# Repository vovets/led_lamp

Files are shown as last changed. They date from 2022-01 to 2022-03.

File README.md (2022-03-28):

# led_lamp

Slightly overengineered battery powered LED lamp for reading

## Introduction

The project was born when I acquired a battery powered lamp for reading and very soon found its deficiencies.

* It changed brightness as battery drained.
* It had only 2 brightness level, both too bright.
* Its efficiency which I define as a ratio of power coming to LED to power coming from battery is only 0.7.

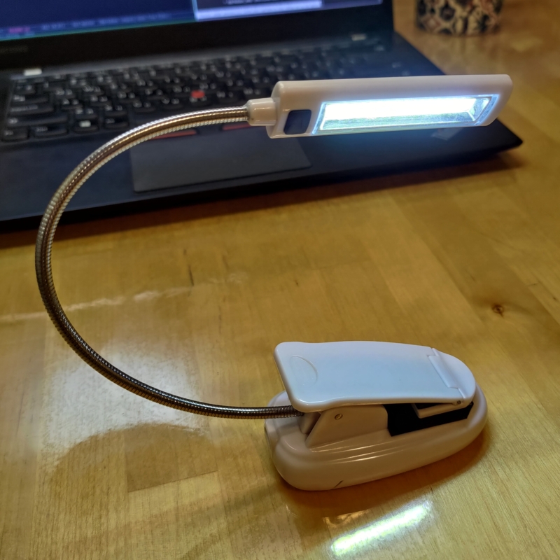
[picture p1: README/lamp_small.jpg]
The Lamp


So I decided to implement my own led driver with mcu control. It actually required some iterations of software and hardware to come up with what is being described here.

## Requirements

* The brightness should be constant as long as the battery voltage under load is higher than some sensible threshold, say 3V. As battery is drained further brightness may gradually decrease.
* When the battery voltage decreases lower than some defined threshold lamp should provide visual indication that battery needs replacement or charging.
* There should be UI for setting the desired brightness level. The brightness levels may be discreet but then there should be enough different levels. The selected brightness level must be kept across the lamp ON-OFF cycles.
* When the battery is completely drained the lamp should clearly indicate this fact and then turn off to prevent battery damage. Lamp should not turn on with a drained battery but provide indication of the flat battery if possible.
 
## Hardware

The lamp consists of "base" with usb connector and batteries, and "head" with a LED panel and a tactile button. The head connected with the base using flexible metallic tube.

### Original hardware

Original electronics consists of two pcbs, one in head and one in base.
The one in the base contains a usb connector, a diode which blocks current from battery to usb VBUS and a 2 Ohm series resistor.
The head pcb contains unmarked chip which obviously provides PWM capability and on/off/mode logic. The LED panel is controlled by a n-channel mosfet. The gate of the mosfet is controlled by the chip. There is also 2 Ohm resistor in series with LED. I assume that the chip is a some obscure uC and there is no LED current limiting except for series resistors.

### Custom hardware

My custom hardware consists of one pcb which contains all the active elements. I also used original pcbs for passive connections. The original base board is used with all parts removed except USB connector. The original head pcb is also cleared of original parts except the button switch and modified using knife and modwire to provide necessary connections. 3 thin wires run inside the connecting tube.

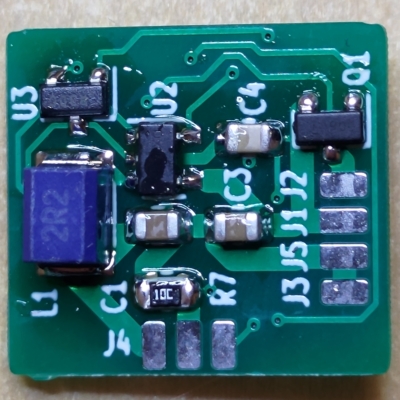
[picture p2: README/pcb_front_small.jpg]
PCB Front
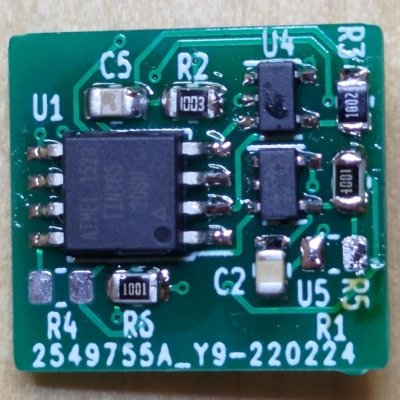
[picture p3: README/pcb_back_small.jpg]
PCB Back
 

*My custom pcb front and back respectively*

### Custom hardware schematics discussion

The parts I used to design the schematics are those I had at my disposal and/or could easyly source locally.

#### DC-DC converter

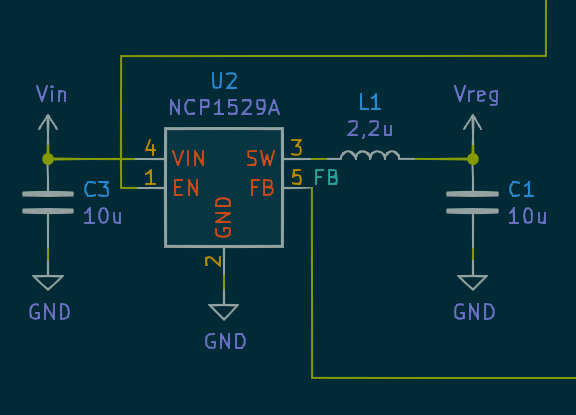
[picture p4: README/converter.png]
DC-DC buck converter


This is the module that provides LED current regulation. Efficiency of the whole device depends mostly on this module.
[Converter chip](hw/datasheet/NCP1529.pdf) may be disabled by MCU via EN pin. In disabled state it consumes just 0.3 uA. Output voltage is controlled by voltage on the FB pin. It is connected to the LED current amplifier.

#### LED current amplifier

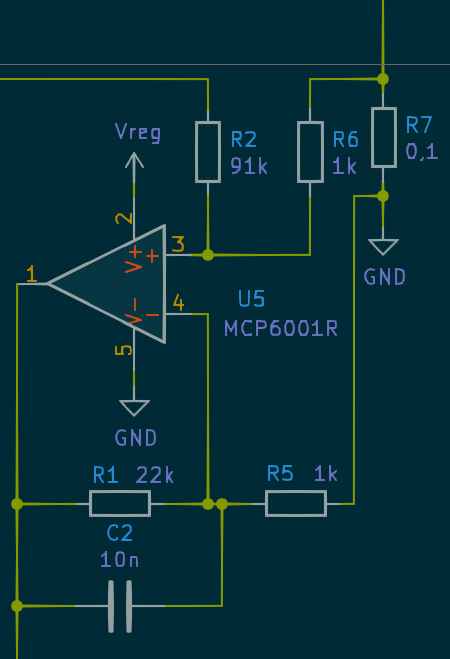
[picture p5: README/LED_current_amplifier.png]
LED current amplifier


The LED current amlifier is built using [MCP6001R](hw/datasheet/MCP6001_1R_1U_2_4.pdf "MCP6001R") CMOS opamp. It amplifies voltage drop on 0.1 Ohm current sensing resistor *R7*, which is fed to the non-inverting input. The non-inverting input is also biased by the DAC module output voltage via *R2*. This arrangement allows to set current regulation point by programming DAC output. When DAC output is 0V, amplifier outputs 0.6V for 250mA LED current. When the voltage on DAC output is at max, which is slightly below 2.5V, the current regulated at approximately 10mA point. It corresponds to the lowest brightness of the lamp.
So the maximum current is 250mA and the minimum is 10mA.

#### DAC

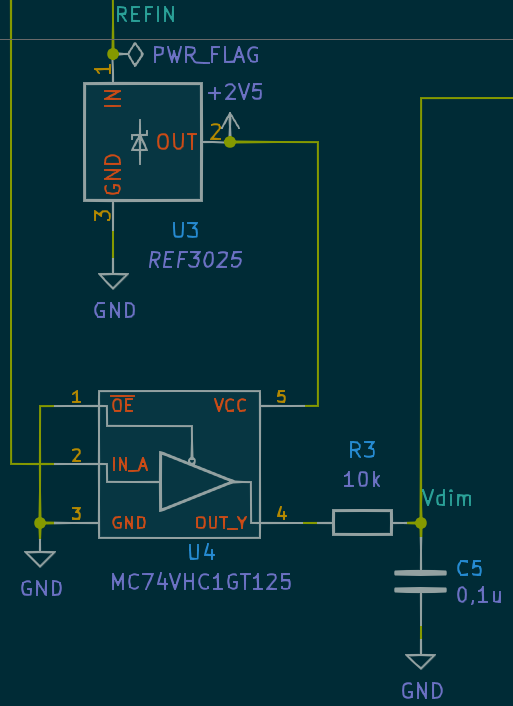
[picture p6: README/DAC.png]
DAC


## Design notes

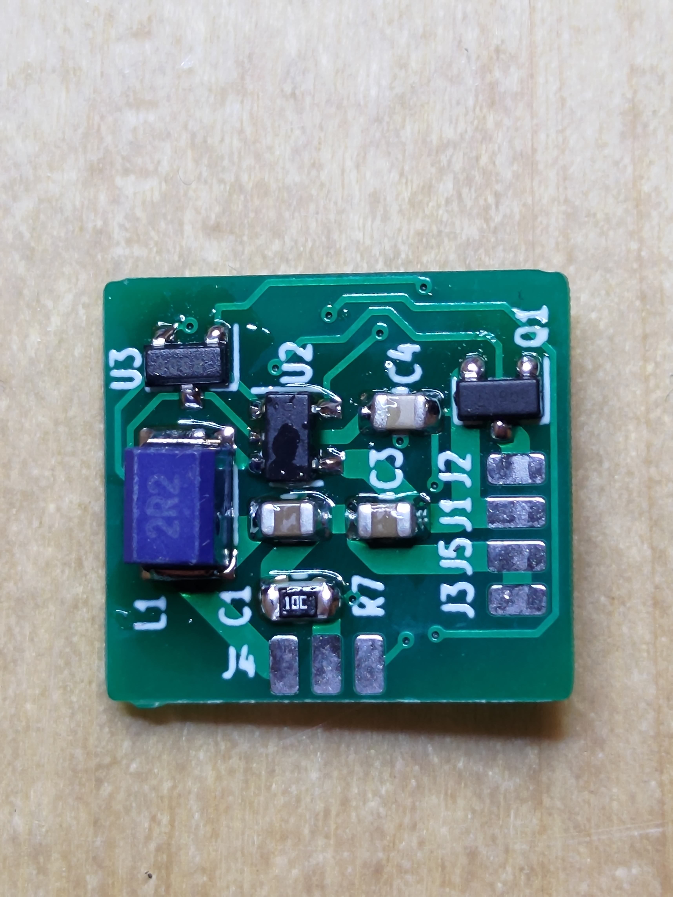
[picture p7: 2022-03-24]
README/pcb_front.jpg

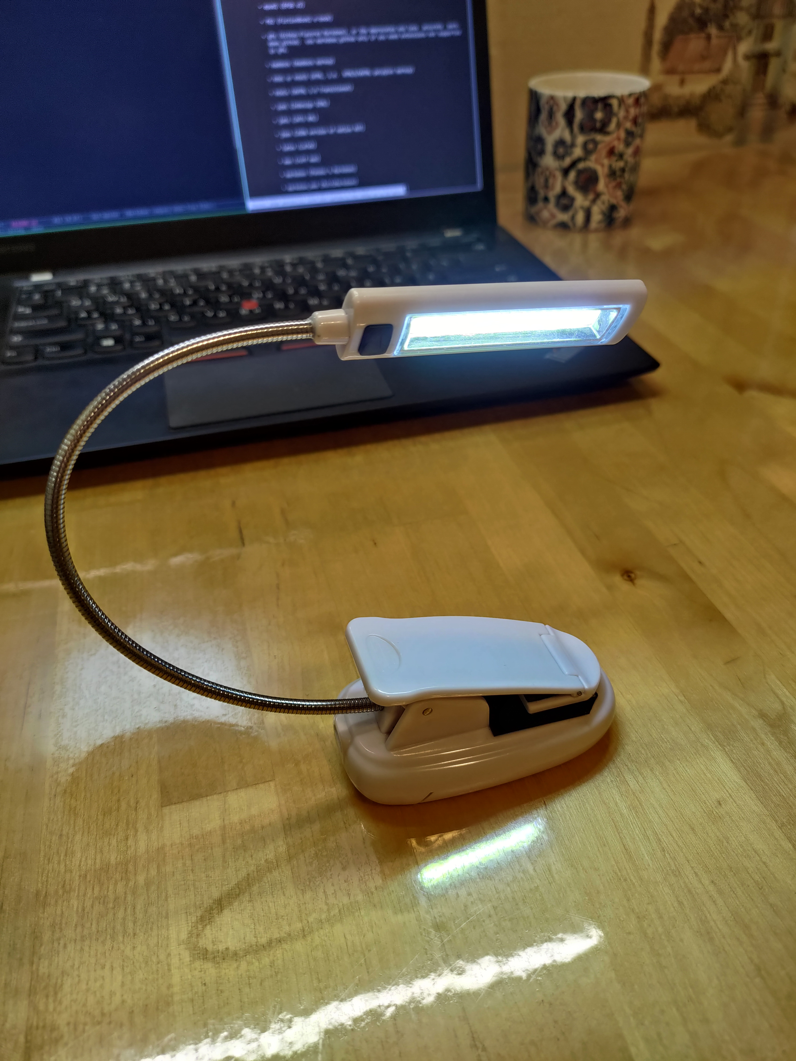
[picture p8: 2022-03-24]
README/lamp.jpg

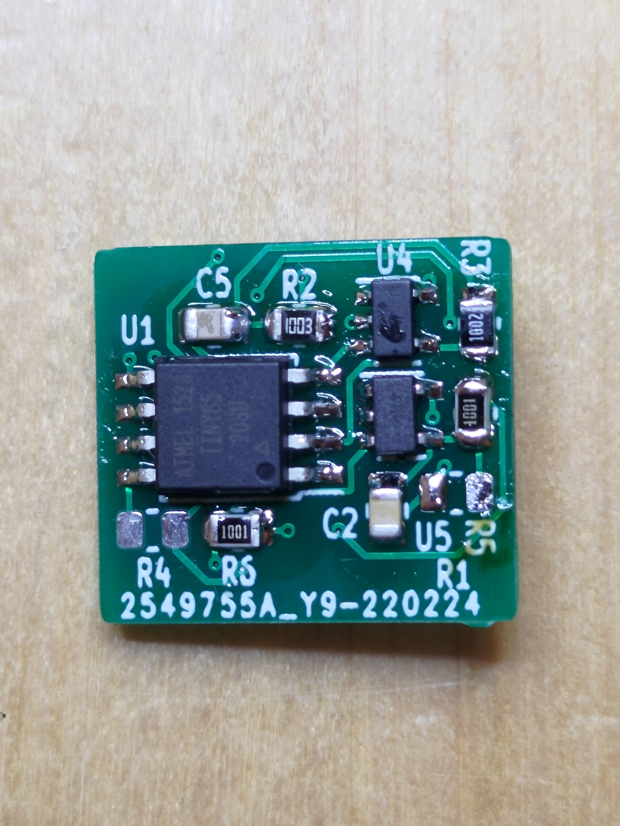
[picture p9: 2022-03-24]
README/pcb_back.jpg

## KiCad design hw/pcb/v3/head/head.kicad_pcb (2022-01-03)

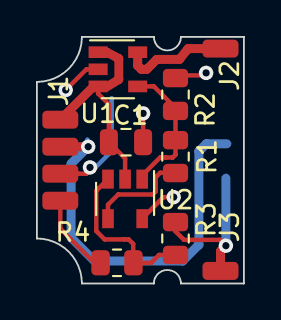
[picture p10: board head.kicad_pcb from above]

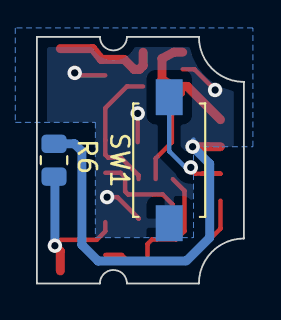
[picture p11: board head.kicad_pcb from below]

Board: 2 copper layers, 11.5 x 13.7 mm, 12 parts (2 on the bottom side), 9 nets.

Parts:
C1: 100n; C_0805_2012Metric
J1: Conn_01x04; SolderWirePad_1x04_SMD_1x2mm
J2, J3: Conn_01x01; SolderWirePad_1x01_SMD_1x2mm
R1: 39k; R_0805_2012Metric
R2, R3: 1k; R_0805_2012Metric
R4: 150k; R_0805_2012Metric
R6: 0,1; R_0805_2012Metric
SW1: SW_Push; SW_SPST_UNKNOWN
U1: TPS73601DBV; SOT-23-5
U2: MCP6001R; SOT-23-5

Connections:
/FB: R1.2, R2.1, U1.4, U2.1
/OUT: J2.1, U1.5
/SW: J1.3, SW1.2
/Vpwm: J1.4, R4.1
GND: C1.2, J1.2, R2.2, R6.2, SW1.1, U1.2, U2.5
unnamed: J3.1, R3.1, R6.1
unnamed: R1.1, U2.4
unnamed: R3.2, R4.2, U2.3
Vreg: C1.1, J1.1, U1.1, U1.3, U2.2

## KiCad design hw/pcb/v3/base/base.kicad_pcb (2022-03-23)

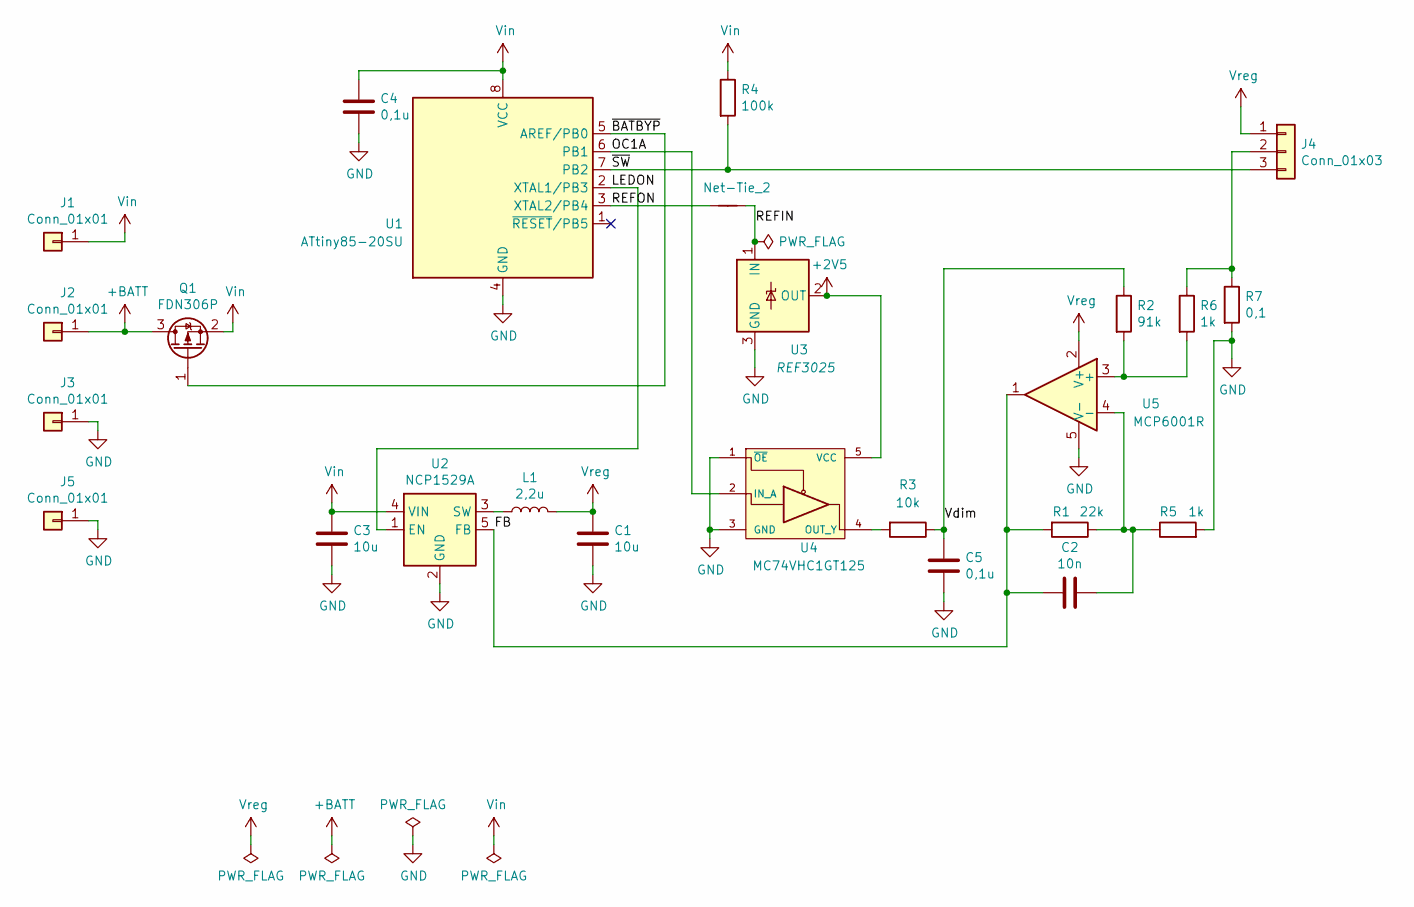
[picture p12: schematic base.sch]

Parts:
C1, C3: 10u; C_0805_2012Metric
C2: 10n; C_0805_2012Metric
C4, C5: 0,1u; C_0805_2012Metric
J1, J2, J3, J5: Conn_01x01; SolderWirePad_1x01_SMD_1x2mm
J4: Conn_01x03; SolderWirePad_1x03_SMD_1x2mm
L1: 2,2u; L_1812_4532Metric
NT1: Net-Tie_2; NetTie-2_SMD_Pad0.5mm
Q1: FDN306P; SOT-23
R1: 22k; R_0805_2012Metric
R2: 91k; R_0805_2012Metric
R3: 10k; R_0805_2012Metric
R4: 100k; R_0805_2012Metric
R5, R6: 1k; R_0805_2012Metric
R7: 0,1; R_0805_2012Metric
U1: ATtiny85-20SU; SOIJ-8_5.3x5.3mm_P1.27mm
U2: NCP1529A; SOT-23-5
U3: REF3025; SOT-23
U4: MC74VHC1GT125; SOT-23-5
U5: MCP6001R; SOT-23-5

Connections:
+2V5: U3.2 (OUT), U4.5 (VCC)
+BATT: J2.1, Q1.3 (D)
/FB: C2.2, R1.2, U2.5 (FB), U5.1
/LEDON: U1.2 (XTAL1/PB3), U2.1 (EN)
/OC1A: U1.6 (PB1), U4.2 (IN_A)
/REFIN: NT1.2, U3.1 (IN)
/REFON: NT1.1, U1.3 (XTAL2/PB4)
/Vdim: C5.1, R2.1, R3.1
/~BATBYP: Q1.1 (G), U1.5 (AREF/PB0)
/~SW: J4.3, R4.2, U1.7 (PB2)
GND: C1.2, C3.2, C4.2, C5.2, J3.1, J5.1, R5.2, R7.2, U1.4 (GND), U2.2 (GND), U3.3 (GND), U4.1 (~OE), U4.3 (GND), U5.5 (V-)
unnamed: C2.1, R1.1, R5.1, U5.4 (-)
unnamed: J4.2, R6.1, R7.1
unnamed: L1.1, U2.3 (SW)
unnamed: R2.2, R6.2, U5.3 (+)
unnamed: R3.2, U4.4 (OUT_Y)
Vin: C3.1, C4.1, J1.1, Q1.2 (S), R4.1, U1.8 (VCC), U2.4 (VIN)
Vreg: C1.1, J4.1, L1.2, U5.2 (V+)

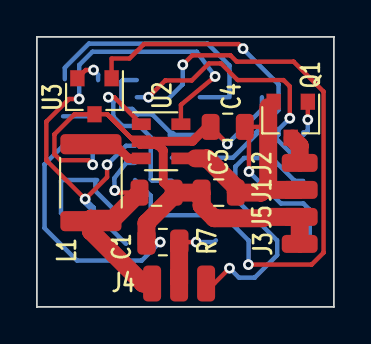
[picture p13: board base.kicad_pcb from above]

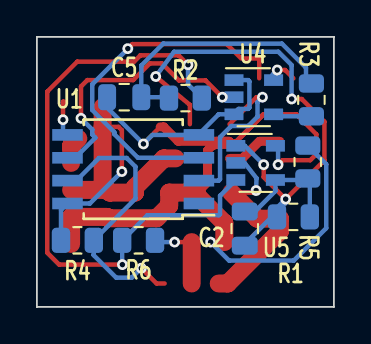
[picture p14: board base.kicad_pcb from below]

Board: 2 copper layers, 16.5 x 15.0 mm, 25 parts (11 on the bottom side), 18 nets.

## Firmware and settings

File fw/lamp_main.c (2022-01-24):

#include <lib/timers.h>
#include <lib/blinker.h>
#include "lib/clocks_etc.h"
#include <lib/button.h>
#include <lib/debouncer.h>
#include <lib/pwm.h>
#include <lib/vcc_monitor.h>
#include "debug.h"
#include <lib/stack_check.h>
#include "loop.h"
#include <lib/pwm_animator.h>

#include <stdint.h>
#include <assert.h>

#include <avr/interrupt.h>


#define BATTERY_BYPASS_PIN PB0
#define OC1A_PIN           PB1
#define SWITCH_PIN         PB2
#define LED_ON_PIN         PB3
#define REF_ON_PIN         PB4
#define LED_ON_IS_HIGH true
#define LOW_VOLTAGE_BLINK_PERIOD_S 60

typedef BtnFunc StateFunc;

static void stateOff(BtnEvent e);
static void stateOn(BtnEvent e);
static void stateSetup(BtnEvent e);
static void vccMonitor(uint16_t mV);
static void turnOff_1(void);

typedef struct State {
    enum StateTag {
        StateOff = 0,
        StateOn,
        StateSetup
    } state;
    uint8_t dimLevel;
    uint16_t prevVoltage; // in mV
    uint16_t lowVoltageBlinkCounter;
} State;

static StateFunc state2func[] = {
    stateOff,
    stateOn,
    stateSetup
};


static uint8_t level2dimPercent[] = {
        100, 75, 50, 25, 0
};

static const uint8_t level2dimPercentSize = sizeof(level2dimPercent) / sizeof(level2dimPercent[0]);

static State state;
static Blinker onOffBlinker;
static Blinker vccmBlinker;

static void setState(enum StateTag s) {
    debugTrace2(debugState, s);
    state.state = s;
}

void setupDebug(void) {
    debugTraceEnableIds(
            (uint32_t)0
//            | bits(debugEvPut)
//            | bits(debugEvGet)
//            | bits(debugBtnToggle)
//            | bits(debugBtnEvent)
//            | bits(debugDbnCounter)
//            | bits(debugTimerExpired)
//            | bits(debugTimerSet)
//            | bits(debugTimerCancel)
//            | bits(debugAlarmEnabled)
//            | bits(debugAlarmDisabled)
//            | bits(debugEnterSleep)
//            | bits(debugExitSleep)
//            | bits(debugVccm)
//            | bits(debugState)
//            | bits(debugAdcStartConversion)
            | bits(debugPwm)
    );
}

void initState(void) {
    state.prevVoltage = 0;
}

static void setupPins(void) {
    DDRB |= _BV(OC1A_PIN);
    DDRB |= _BV(BATTERY_BYPASS_PIN);
    DDRB |= _BV(LED_ON_PIN);
    DDRB |= _BV(REF_ON_PIN);
    // disable digital input on all 5 pins except...
    DIDR0 = 0x1FU & ~_BV(SWITCH_PIN);
}

static void setupPCINT(void) {
    PCMSK |= _BV(SWITCH_PIN);
}

static void led(bool on) {
    if (on == LED_ON_IS_HIGH) {
        PORTB |= _BV(LED_ON_PIN);
    } else {
        PORTB &= ~_BV(LED_ON_PIN);
    }
}

static void ref(bool on) {
    if (on) {
        PORTB |= _BV(REF_ON_PIN);
    } else {
        PORTB &= ~_BV(REF_ON_PIN);
    }
}

static void bypass(bool on) {
    if (on) {
        PORTB &= ~_BV(BATTERY_BYPASS_PIN);
    } else {
        PORTB |= _BV(BATTERY_BYPASS_PIN);
    }
}

static uint8_t calculatePwm(uint8_t pwmLevel) {
    uint16_t dimPercent = level2dimPercent[pwmLevel];
    return (dimPercent * 255U) / 100U;
}

static void updatePwm(void) {
    pwmaStart(calculatePwm(state.dimLevel), NULL);
}

static void updateBypass(uint16_t mV) {
    const uint8_t hist = 5;
    int16_t delta = mV - state.prevVoltage;
    if (abs(delta) <= hist) {
        return;
    }
    state.prevVoltage = mV;
    bypass(mV < 4500U);
}

static void vccmBlinkerSetup(uint8_t iterations) {
    blinkerSetup(&vccmBlinker, BlinkerModeOffThenOn, iterations, ST_MS2TICKS(50), ST_MS2TICKS(100), &led);
}

static void vccmBlinkerFinished(Blinker* blinker, void* off) {
    if (off) {
        turnOff_1();
    }
}

static void checkLowVoltage(uint16_t mV) {
    if (mV < 2700) {
        vccmBlinkerSetup(5);
        blinkerStart(&vccmBlinker, &vccmBlinkerFinished, (void*)1);
    } else if (mV >= 2700 && mV < 3100) {
        if (state.lowVoltageBlinkCounter) {
            --state.lowVoltageBlinkCounter;
        } else {
            state.lowVoltageBlinkCounter = (LOW_VOLTAGE_BLINK_PERIOD_S * 1000UL) / VCC_MONITOR_PERIOD_MS;
            vccmBlinkerSetup(3);
            blinkerStart(&vccmBlinker, &vccmBlinkerFinished, (void*)0);
        }
    }
}

static void vccMonitor(uint16_t mV) {
    debugTrace2(debugVccm, mV);
    updateBypass(mV);
    checkLowVoltage(mV);
    vccmContinue(&vccMonitor);
}

static void setupBlinker(void) {
    blinkerSetup(&onOffBlinker, BlinkerModeOffThenOn, 1, ST_MS2TICKS(100), ST_MS2TICKS(400), &led);
}

static void startBlinker(void) {
    if (!blinkerIsActive(&onOffBlinker)) {
        blinkerStart(&onOffBlinker, 0, 0);
    }
}

static void stopBlinker(void) {
    if (blinkerIsActive(&onOffBlinker)) {
        blinkerStop(&onOffBlinker);
    }
}

static void turnOn(void) {
    setState(StateOn);
    ref(true);
    pwmSet(255U);
    pwmEnable();
    vccmEnable();
    vccmStart(&vccMonitor);
    led(true);
    updatePwm();
}

static void turnOff_1(void) {
    setState(StateOff);
    vccmDisable();
    state.lowVoltageBlinkCounter = 0;
    stopBlinker();
    led(false);
    ref(false);
    pwmaStop();
    pwmDisable();
}

static void turnOff_0(void) {
    pwmaStart(255, &turnOff_1);
}

static void enterSetup() {
    setState(StateSetup);
    startBlinker();
}

static void exitSetup(void) {
    setState(StateOn);
    startBlinker();
}

static void nextLevel(void) {
    state.dimLevel = (state.dimLevel + 1) % level2dimPercentSize;
    updatePwm();
}

static void stateOff(BtnEvent e) {
    switch (e) {
        case BtnShortPress:
            turnOn();
            break;

        default:
            ;
    }
}

static void stateOn(BtnEvent e) {
    switch (e) {
        case BtnShortPress:
            turnOff_0();
            break;

        case BtnLongPress:
            enterSetup();
            break;

        default:
            ;
    }
}

static void stateSetup(BtnEvent e) {
    switch (e) {
        case BtnLongPress:
            exitSetup();
            break;

        case BtnShortPress:
            nextLevel();
            break;

        default:
            ;
    }
}

uint8_t sleepMode(void) {
    if (state.state == StateOff && !stIsAlarmSet()) {
        return SLEEP_MODE_PWR_DOWN;
    }
    return SLEEP_MODE_IDLE;
}

static void buttonEvent(BtnEvent e) {
    debugTrace2(debugBtnEvent, e);
    state2func[state.state](e);
}

int main(void) __attribute__ ((noreturn));

int main(void)
{
    setupDebug();
    led(false);
    bypass(false);
    initState();
    setupClock();
    setupPins();
    pwmInit();
    stInit();
    tmInit();
    btnInit(SWITCH_PIN, buttonEvent);
    setupPCINT();
    setupBlinker();
    vccmInit();
    dbnEnable();
    stEnableClock();
    sei();
    loop();
}

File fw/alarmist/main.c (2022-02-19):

#include <lib/sys_time.h>
#include <lib/clocks_etc.h>
#include <lib/debug.h>
#include <lib/macro_utils.h>
#include <lib/loop.h>
#include <lib/event_queue.h>

#include <stdint.h>
#include <assert.h>

#include <avr/interrupt.h>
#include <avr/sleep.h>
#include <avr/io.h>


#define LED_PIN PB4
#define PERIOD 2

void setupDebug(void) {
    debugTraceEnableIds(
            (uint32_t)0
//            | bits(debugEvPut)
//            | bits(debugEvGet)
            | bits(debugAlarmEnabled)
//            | bits(debugAlarmDisabled)
//            | bits(debugEnterSleep)
//            | bits(debugExitSleep)
    );
}

void setupPins(void) {
    DDRB |= _BV(LED_PIN);
}

static inline void togglePin(uint8_t pin) {
    if (PORTB & _BV(pin)) {
        PORTB &= ~_BV(pin);
    } else {
        PORTB |= _BV(pin);
    }
}

uint8_t sleepMode(void) {
    return SLEEP_MODE_IDLE;
//    return SLEEP_MODE_NONE;
}

void alarm(Event* event) {
    static volatile SysTimePoint prev = 0;
//    debugPinOff(DEBUG_PIN_0);
    togglePin(LED_PIN);
    stSetAlarmAt(event->time + PERIOD);
    SysTimePoint now = stNow();
    assert_(now - event->time < PERIOD - 1);
    assert_(now - prev == PERIOD);
    prev = now;
}

int main(void)
{
    setupDebug();
    debugPinInit();
    setupClock();
    setupPins();
    eqInit();
    stInit();
    stSetAlarmAtI(stNowI() + PERIOD);
    stEnableClock();
    sei();
    while (true) {
        while(processOneEvent()) {
        }
        tryToSleep();
    }
}

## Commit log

2022-01-03 Added v1 pcb, just for reference.
    [base.kicad_pcb, base.sch, head.kicad_pcb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]
2022-01-24 Low voltage blinker period constant is in seconds
2022-02-19 Bugfixes, directory structure changes, refactoring
    * Fixed: use of |= operator with interrupt mask registers. Do not use |= on registers with address > 0x20. SBI instructin work only for addresses < 0x20. Without sbi, compiler generates read-apply_or-write code which actually clears all the set flags.
    * Fixed: use of stNow (instead of stNowI) from interrupt context unintentionally enables interrupts
    * Separate directories for apps, use static include names for per app parameter files
    * Put common files for all apps into lib directory
    * Use panic() for unrecoverable errors and asserts instead of abort()
    * Use assert_() macro
    * Don't emit any debugTrace2 related code if DEBUG_TRACE_BUFF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
    [custom_parameters.h, debug_event_ids.h, main.c]
2022-02-19 Actual working schematics, pcb needs updating. Prototype uses modwires for now.
    * Added simple dac using voltage reference and cmos buffer
    [base.kicad_pcb, base.sch, head.kicad_pcb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]
2022-03-23 Inplemented and tested v3 hardware
    * One base board instead of base and head boards
    * Removed linear regulator
    * 88% efficiency of battery to LED conversion
    [base.kicad_pcb, base.sch, head.kicad_pcb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]
